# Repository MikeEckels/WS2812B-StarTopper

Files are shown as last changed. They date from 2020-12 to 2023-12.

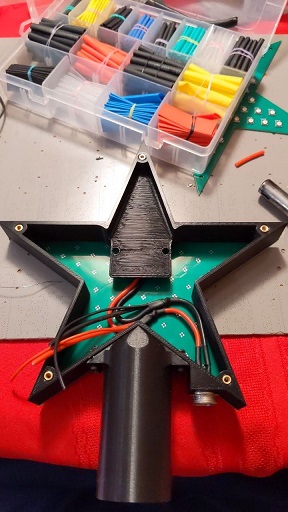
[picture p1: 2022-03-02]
Photos/Star/Wiring.jpg

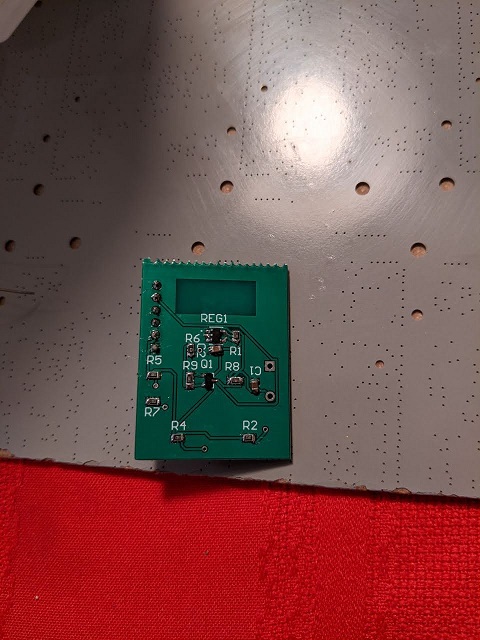
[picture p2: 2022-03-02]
Photos/Star/ESPBack.jpg

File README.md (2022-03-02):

# WS2812B-StarTopper
 RGB Christmas tree star topper with 126 individually adressable WS2812B LED's. The main controller is based off of an esp8266-12E embedded into a custom PCB to provide voltage regulation, 5v<-->3.3v level shifting, and an easy programming interface. Alternatively, the software also supports a standard ESP32Devkit. Other than the custom electronics, everything is 3D-printable.
 
 - [Pictures](https://github.com/MikeEckels/WS2812B-StarTopper/tree/main/Photos)
 - [3D Files](https://github.com/MikeEckels/WS2812B-StarTopper/tree/main/3DFiles)
 - [Altium Files](https://github.com/MikeEckels/WS2812B-StarTopper/tree/main/AltiumFiles)
 
 <p float="left">
  
  
</p>
 
 # Electronics Overview
 All schematics and PCB's were created in Altium Designer. The PCB's were sent to JLCPCB for fabrication. The heart of the system is the ESP8266-12E module. This module was embedded into a small PCB with a BSS138 level shifter for the 5v<-->3.3v conversion between the ESP and the WS2812B LED's. The module also contains a AP2112K-3.3 linear voltage regulator to power the ESP from the main 5V supply. The main star PCB contains 63 WS2812B LED's with power connected in parallel, and thier data lines in series. The ESP board connects to the first stars DIN pin, and the second star's DIN pin connects to the first star's DOUT pin. The entire system is powered by a MeanWell LPV 35-5 powersupply. If a custom PCB is not desired, a standard ESP32Devkit can be used instead.
 
 ## Schematics and Board Files
  - [PCB Files](https://github.com/MikeEckels/WS2812B-StarTopper/blob/main/AltiumFiles/)
  - [Schematic PDF](https://github.com/MikeEckels/WS2812B-StarTopper/blob/main/AltiumFiles/StarTopper.pdf)
  
 ## Power Supply
  - [Purchased Here](https://www.meanwell-web.com/en-gb/ac-dc-single-output-led-driver-constant-voltage-cv-lpv--35--5)
  - [STL's Here](https://github.com/MikeEckels/WS2812B-StarTopper/tree/main/3DFiles/STLs)
  
 # Code Overveiew
 This library provides a simple wrapper around a popular LED control library called [FastLED](https://github.com/FastLED/FastLED). This enables simple and elegant control of every LED on the star as well as the ability to create and sequence patterns. I also developed a network manager to allow for seamless transitions from one network to another. That can be found [here](https://github.com/MikeEckels/EspWifiManager).
 
 ## Features
  - Quick LED addressing using [FastLED](https://github.com/FastLED/FastLED)
  - Seamless network management [EspWifiManager](https://github.com/MikeEckels/EspWifiManager)
  - App control over the network using [Blynk](https://github.com/blynkkk/blynk-library)
 ## Available Functions
  - Star::Begin(): Initialzie all pins and setup network
    - Arguments: None
    - Return: None
  - Star::Update(): Refreshes LED's and device state.
    - Arguments: None
    - Return: None
  - Star::NextPattern(): Ques the next pattern for the next Update() call
    - Arguments: None
    - Return: None
  - Star::LoopPatterns(unsigned int nSeconds) Ques all patterns to automatically change in sequence after nSeconds
    - Arguments: unsigned int nSeconds
    - Return: None
  - Star::SetPattern(unsigned int patternNumber) Ques a specific pattern from the list
    - Arguments: unsigned int patternNumber
    - Return: None
  - Star::SetMode(bool isPattern) sets the display mode (1 = pattern mode, 0 = color mode)
    - Arguments: bool isPattern
    - Return: None
  - Star::SetColor(unsigned int r, unsigned int g, unsigned int b) sets all LEDs on the star to a desired RGB value
    - Arguments: unsigned int r,g,b
    - Reurn: None
  - Star::SetBrightness(unsigned int brightness) sets all LEDs on the star to a desired brightness
    - Arguments: unsigned int brightness
    - Return: None
  - Star::SetFramesPerSecond(unsigned int fps) sets the refresh rate for patterns when in patern mode
    - Arguments: unsigned int fps
    - Return: None
    
 # App Control
 Using the [Blynk](https://github.com/blynkkk/blynk-library) arduino library and accompanying android and apple app, a simple user interface can be made. This allows for multiple types of widgets to be setup to transfer data back and fourth between the star and the app. In this simple setup, a color picker, a brightness slider, and a pattern mode button are used to give simple wireless functionality to the star. A Terminal widget is also used to display debug/status information.
 


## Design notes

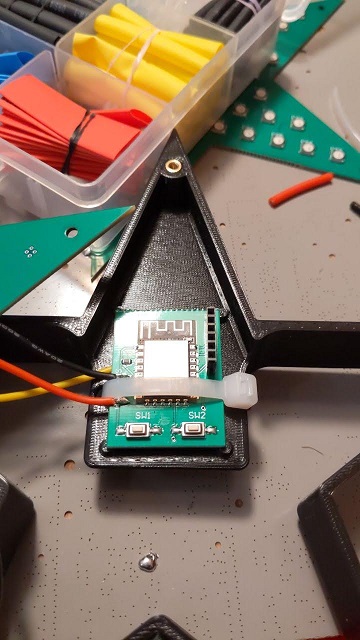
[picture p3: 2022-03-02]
Photos/Star/AttachingESP.jpg

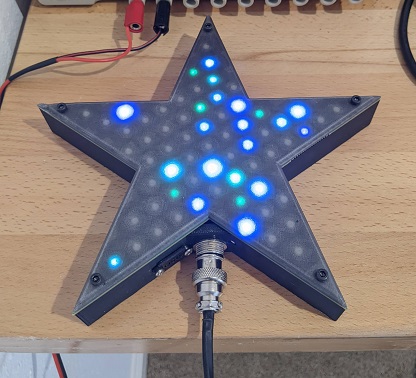
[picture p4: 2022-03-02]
Photos/Star/Version2.jpg

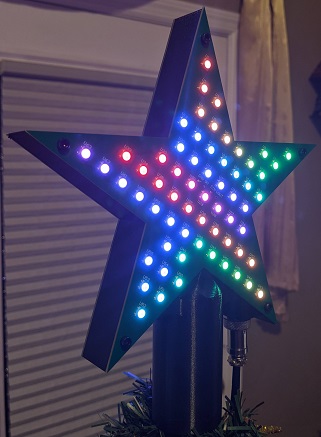
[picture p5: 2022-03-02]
Photos/Star/FinishedStar.jpg

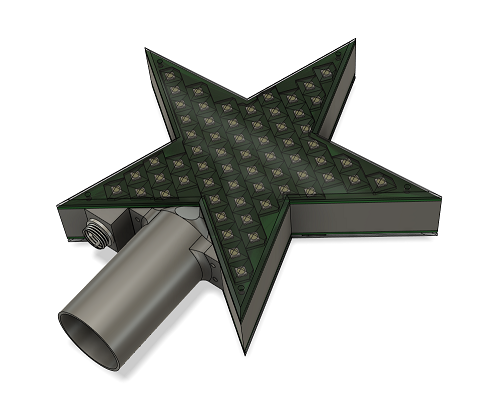
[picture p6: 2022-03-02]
Photos/Star/3DModel.PNG

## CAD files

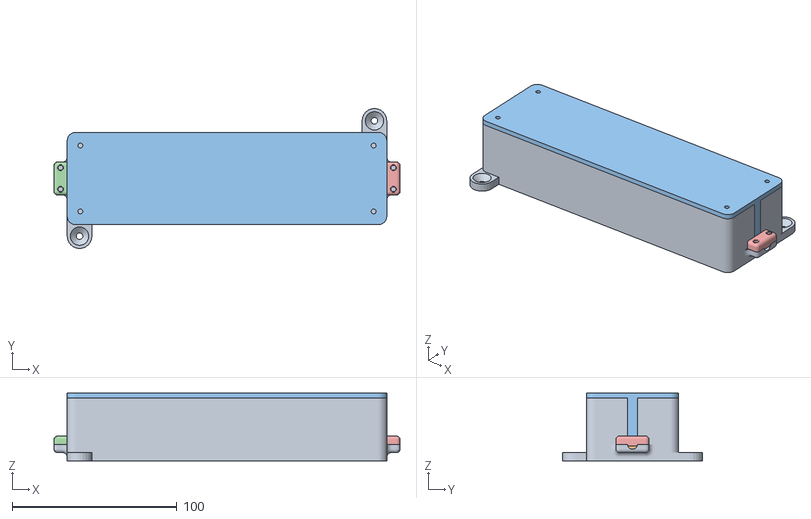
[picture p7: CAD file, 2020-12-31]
3DFiles/OBJs/PowerSupply/PSUBox.obj
210.0 x 85.0 x 41.0

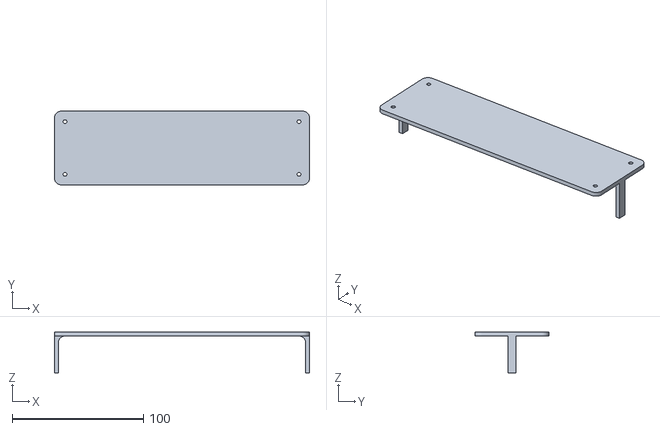
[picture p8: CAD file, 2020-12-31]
3DFiles/STLs/PowerSupply/Lid.stl
194.0 x 56.0 x 31.0

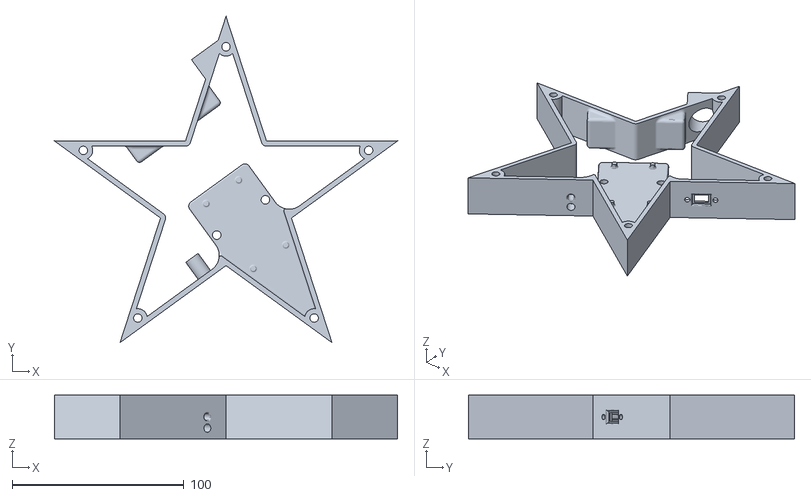
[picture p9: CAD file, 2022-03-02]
3DFiles/STLs/StarV2/Frame.stl
199.7 x 189.9 x 25.4

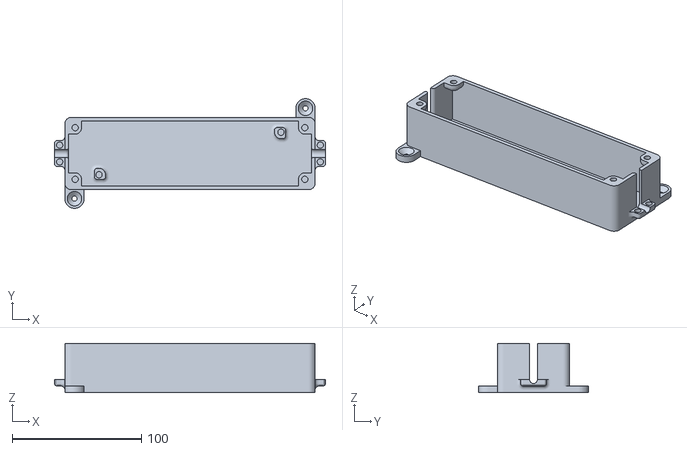
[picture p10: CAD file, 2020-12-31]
3DFiles/STLs/PowerSupply/Box.stl
210.0 x 85.0 x 38.0

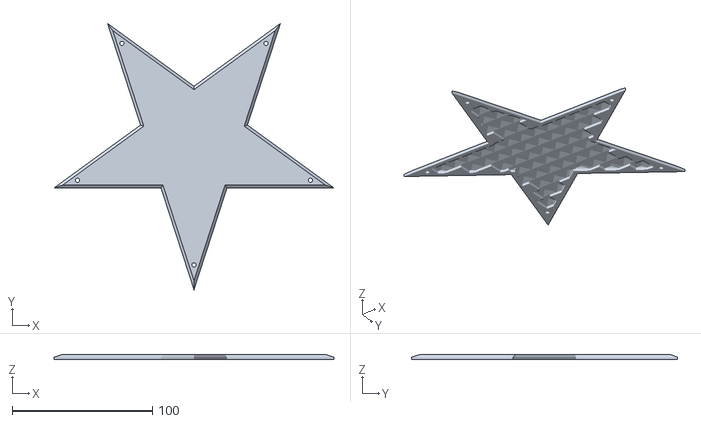
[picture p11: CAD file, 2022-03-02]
3DFiles/STLs/StarV2/Cover.stl
199.7 x 189.9 x 3.70

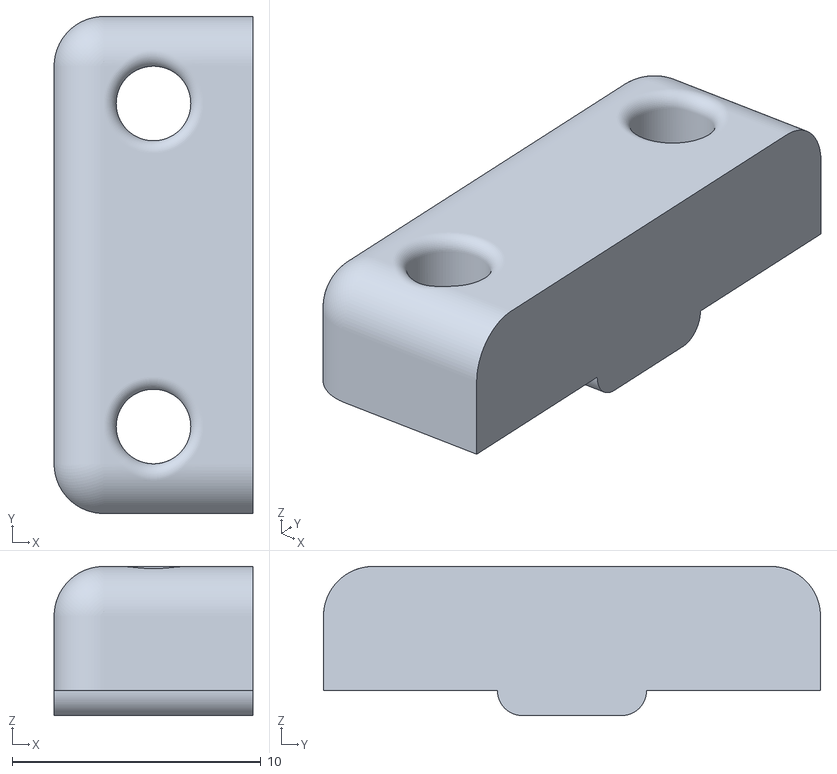
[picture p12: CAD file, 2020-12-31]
3DFiles/STLs/PowerSupply/CableRestraint.stl
8.00 x 20.0 x 6.00

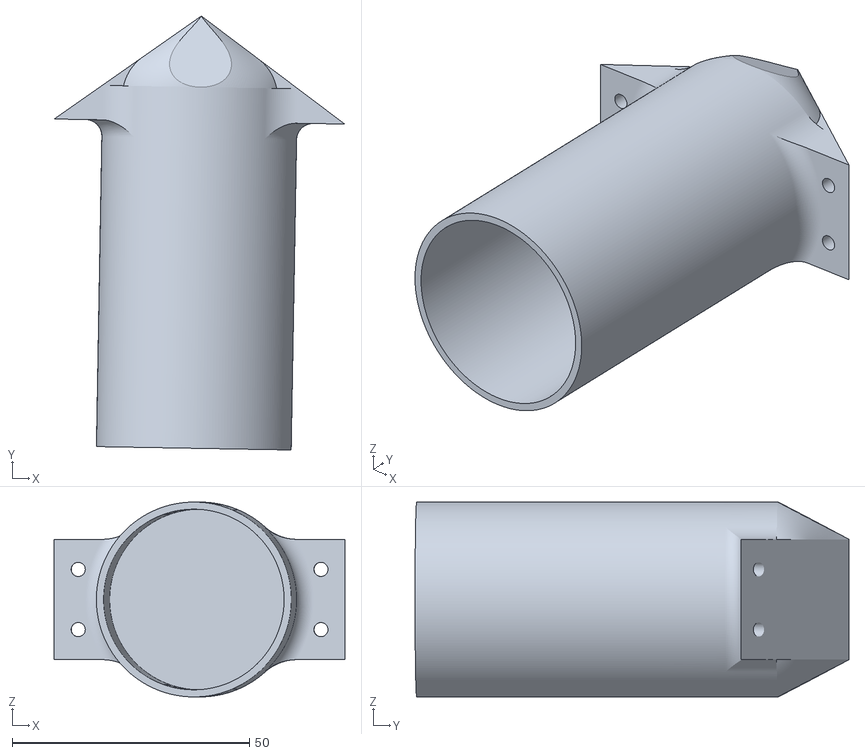
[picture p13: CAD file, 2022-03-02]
3DFiles/STLs/StarV2/PoleMount.stl
61.3 x 91.5 x 41.1

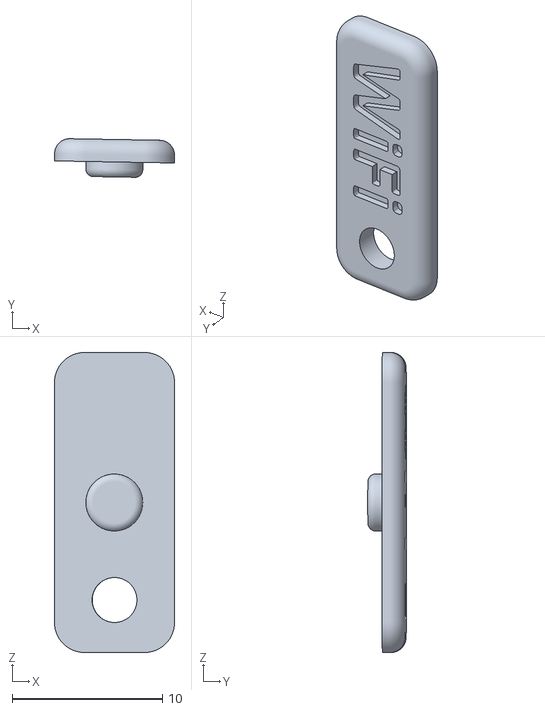
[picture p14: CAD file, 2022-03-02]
3DFiles/STLs/StarV2/ResetCover.stl
8.01 x 2.58 x 20.0

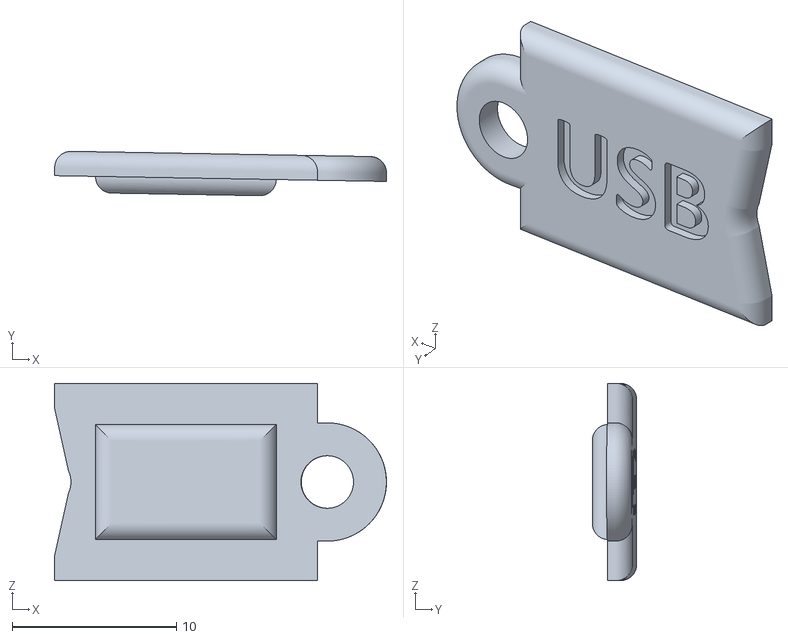
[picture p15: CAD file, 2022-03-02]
3DFiles/STLs/StarV2/USBCover.stl
20.2 x 2.70 x 12.0

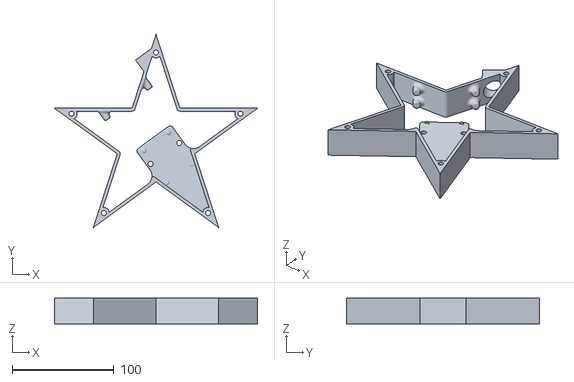
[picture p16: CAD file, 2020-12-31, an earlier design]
3DFiles/STLs/StarV1/Frame.stl
199.7 x 189.9 x 25.4

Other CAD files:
3DFiles/STLs/StarV1/PoleMount.stl
3DFiles/OBJs/PowerSupply/PSUBox.f3z
3DFiles/StarTopperV1.f3z

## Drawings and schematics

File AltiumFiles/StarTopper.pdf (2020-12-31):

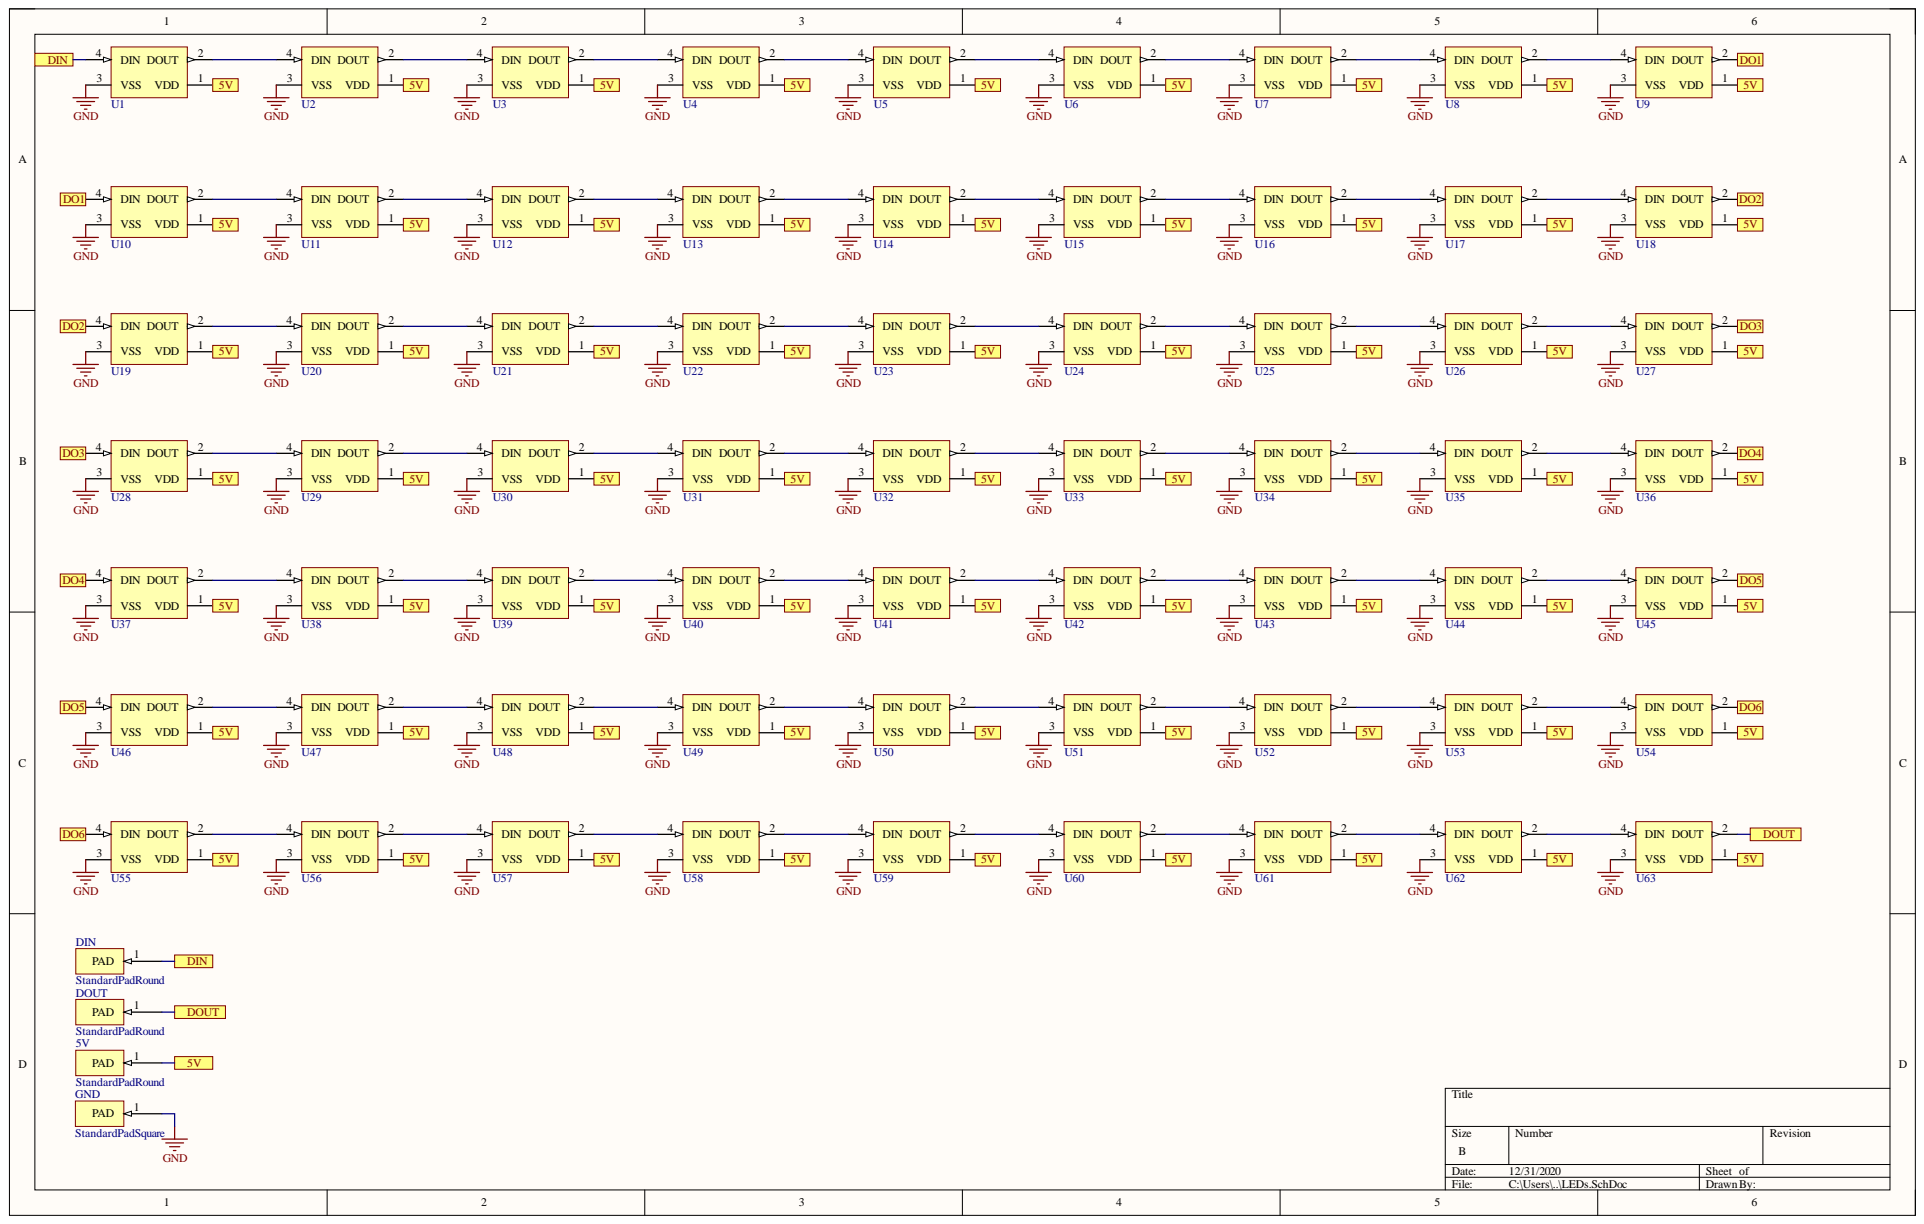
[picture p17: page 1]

DO4 | VSS 3 | VSS 3 | VSS 3 | VSS 3 | VSS 3 | VSS 3 | VSS 3 | VSS 3 | VSS 3 | DO5

DO5 | VSS 3 | VSS 3 | VSS 3 | VSS 3 | VSS 3 | VSS 3 | VSS 3 | VSS 3 | VSS 3 | DO6

DO6 | VSS 3 | VSS 3 | VSS 3 | VSS 3 | VSS 3 | VSS 3 | VSS 3 | VSS 3 | VSS 3 | DOUT

Size B | Number | Revision

Date: 12/31/2020 | Sheet of
File: C:\Users\..\LEDs.SchDoc | Drawn By:

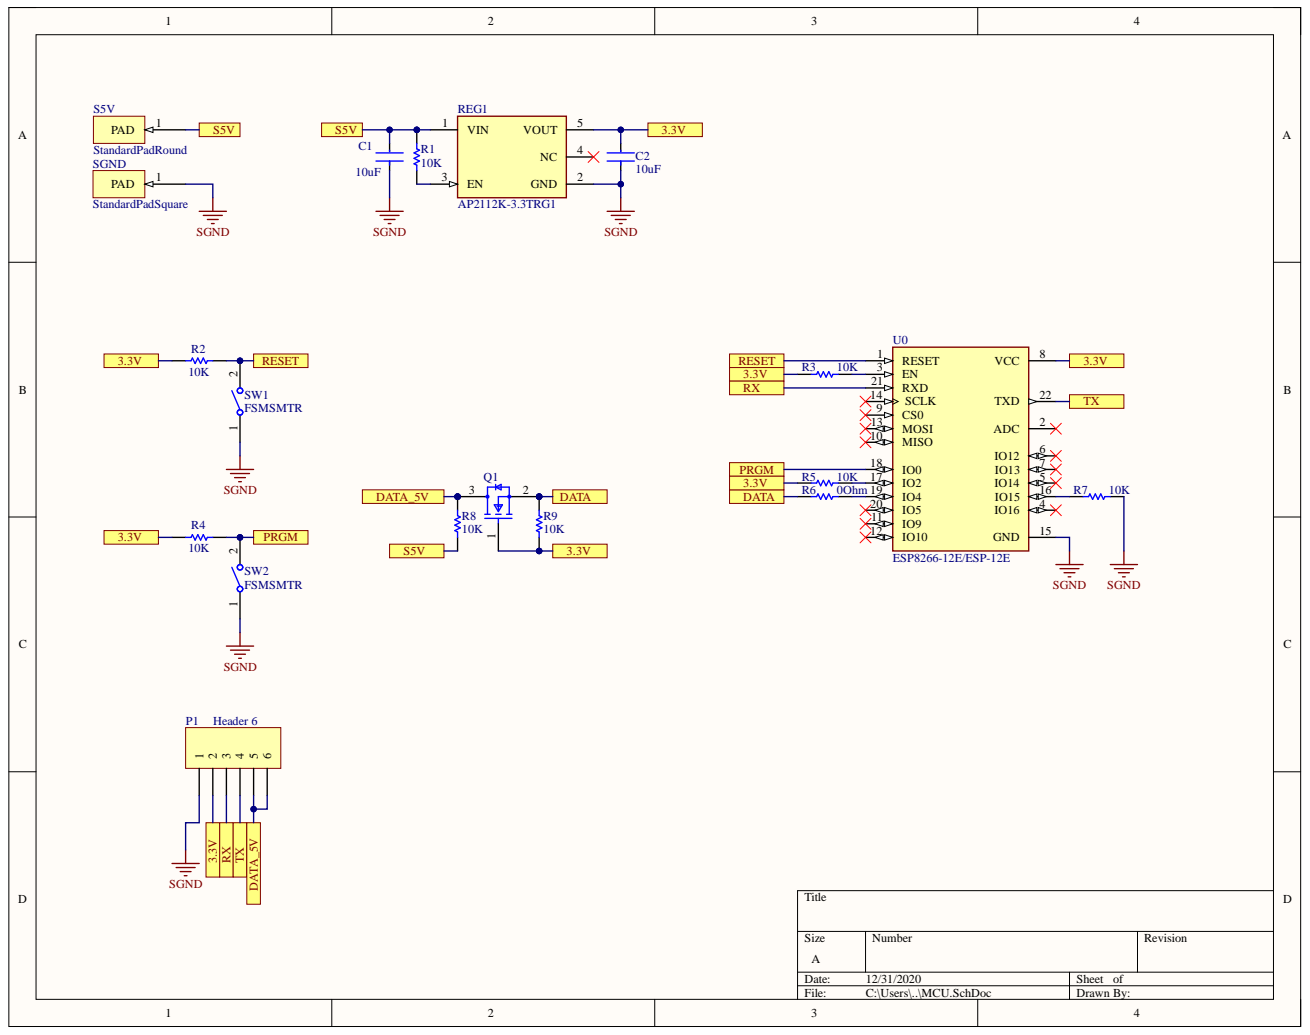
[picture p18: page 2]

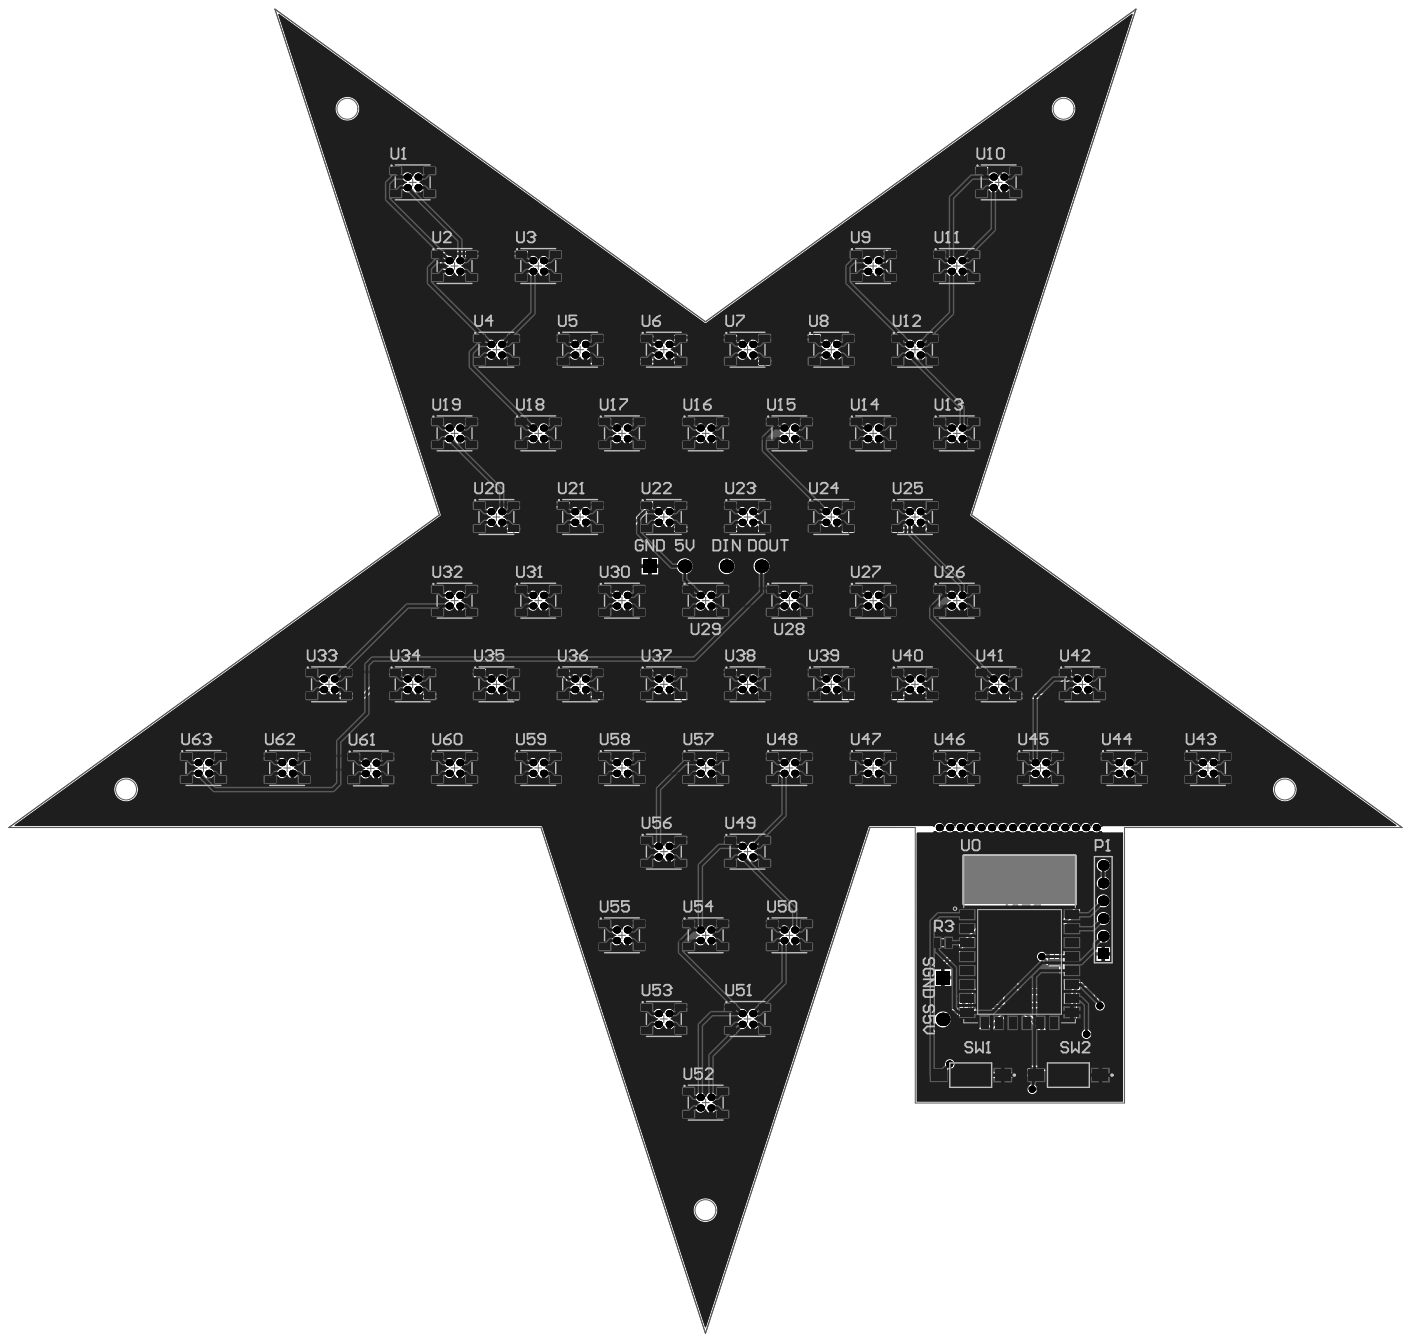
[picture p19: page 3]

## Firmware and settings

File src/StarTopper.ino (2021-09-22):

#include "Star.h"

Star StarTopper;

void setup() {
	Serial.begin(115200);
	StarTopper.begin();

	/*Either set pattern mode with a brightness*/
	StarTopper.SetMode(1);
	StarTopper.SetBrightness(50);

	/*Or set color mode with a brightnessand colors*/
	//StarTopper.SetMode(0);
	//StarTopper.SetBrightness(50);
	//StarTopper.SetColor(255, 0, 70);

	StarTopper.SetFramesPerSecond(120);

	/*If in pattern mode you can chose a specific pattern to start on(0 - 8)
	Or repeat forever if not using "LoopPatterns()"*/
	//StarTopper.SetPattern(7);
}

void loop() {
	StarTopper.Update();
	StarTopper.LoopPatterns(10);
}

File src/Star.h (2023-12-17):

#ifndef STAR_H
#define STAR_H

//#define DEV_TOPPER
//#define CHRIS_TOPPER
#define MOM_TOPPER

#ifdef DEV_TOPPER
#define BLYNK_TEMPLATE_ID "TMPLsSXg8uS6"
#define BLYNK_TEMPLATE_NAME "DevStarTopper"
#endif

#ifdef CHRIS_TOPPER
#define BLYNK_TEMPLATE_ID "TMPLsvLCbD74"
#define BLYNK_TEMPLATE_NAME "ChrisStarTopper"
#endif

#ifdef MOM_TOPPER
#define BLYNK_TEMPLATE_ID "TMPL2FI4gYD1A"
#define BLYNK_TEMPLATE_NAME "StarTopper"
#endif

#include "Arduino.h"

#ifdef ESP8266
//#include <BlynkSimpleEsp8266.h>
#include <BlynkSimpleEsp8266Fixed.h>
#define FASTLED_ESP8266_RAW_PIN_ORDER
#elif defined(ESP32)
//#include <BlynkSimpleEsp32.h>
#include <BlynkSimpleEsp32Fixed.h>
#else
#error "Unsupported Board Type. Please use ESP8266 or ESP32"
#endif

#include<functional>
#include <FastLED.h>
#include <WifiManager.h>

#define ARRAY_SIZE(A) (sizeof(A) / sizeof((A)[0]))

static bool callBlynkOnce;
static WidgetTerminal terminal(V6);

static struct colorParams_t {
	unsigned int hue = 0;
	unsigned int red = 0;
	unsigned int blue = 0;
	unsigned int green = 0;
	unsigned int brightness = 20;
}colorParams;

class Star {
private:
	//WifiManager Network Definitions
	char auth[33];
	String espSSIDPrefix = "StarTopper";
	String espPass = "";
	static const unsigned char wifiResetPin = 5;
	static const unsigned char randomSeedPin = A0;
	WifiManager networkManager;// = WifiManager(wifiResetPin, randomSeedPin);

	//Hardware Definitions
	static const unsigned char pin = 4;
	static const EOrder colorOrder = GRB;
	static const LEDColorCorrection colorCorrection = TypicalSMD5050;
	unsigned int framesPerSecond = 120;

	//Array Sizes
	static const unsigned int numPoints = 5;
	static const unsigned int numLEDsTotal = 126;
	static const unsigned int numLEDsBorder = 42;
	static const unsigned int numLEDsPerPoint = 9;
	static const unsigned int numLEDsMiddle = (numLEDsTotal / 2) - (numLEDsPerPoint * numPoints);

	//LED Arrays
	CRGB leds[numLEDsTotal];
	const unsigned int ledBorder[numLEDsBorder] = {0, 1, 2, 4, 5, 6,
												   7, 8, 9, 10,11,12,
												   24,25,40,41,42,43,
												   44,45,46,45,48,49,
												   50,51,52,54,55,57,
												   58,59,60,61,62,32,
												   33,31,19,18,3, 1};

	const unsigned int ledMiddle[numLEDsMiddle] = {16,15,14,20,21,22,
												   23,30,29,28,27,26,
												   35,36,37,38,57,56};

	const unsigned int points[numPoints][numLEDsPerPoint] = {{0, 1, 2, 3, 4, 5, 18,17,19},
															 {6, 7, 8, 9, 10,11,12,13,24},
															 {25,39,40,41,42,43,44,45,46},
															 {48,49,50,51,52,53,54,55,47},
															 {31,32,33,34,58,59,60,61,62}};

	//Member Function Pointer Array
	typedef void (Star::* tpatternFn) ();
	tpatternFn patterns[9] = { &Star::TracePattern,    &Star::BouncePattern,    &Star::JugglePattern,
							   &Star::RainbowPattern,  &Star::GRainbowPattern,  &Star::ConfettiPattern,
							   &Star::PinwheelPattern, &Star::StarburstPattern, &Star::RasterizePattern };
	
	//Visual Parameters
	bool apError = false;
	bool patternMode = 0;
	unsigned int currentPattern = 0;

	void WifiError();
	void TracePattern();
	void BouncePattern();
	void JugglePattern();
	void RainbowPattern();
	void GRainbowPattern();
	void ConfettiPattern();
	void PinwheelPattern();
	void StarburstPattern();
	void RasterizePattern();
	void AddGlitter(fract8 chance);

	void WifiResetCallback(void);
	void WifiLoadingCallback(int status);

public:
	Star();
	void begin();
	void Update();
	void NextPattern();
	void LoopPatterns(unsigned int nSeconds);

	bool blynkConnected = false;
	bool disconnectError = false;
	
	bool GetMode();
	colorParams_t GetColors();

	void SetPattern(unsigned int patternNumber);
	void SetMode(bool isPattern);
	void SetColor(unsigned int r, unsigned int g, unsigned int b);
	void SetBrightness(unsigned int brightness);
	void SetFramesPerSecond(unsigned int fps);

};

#endif //STAR_H

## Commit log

2020-12-31 added altium files and changed src directory
    [LEDs.SchDoc, MCU.SchDoc, Star.PcbDoc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]
2020-12-31 Added 3D files
    [Frame.stl, PoleMount.stl, StarTopper.f3z]
2020-12-31 added power supply 3D models
    [Box.stl, CableRestraint.stl, Frame.stl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]
2020-12-31 Removed .obj form gitignore
    [PSUBox.obj]
2021-08-24 Updated to use library, added error state
    [Star.h]
2021-09-14 Fixed callbacks to not require static methods
    [Star.h]
2021-09-22 Fixed server sync issues
    [Star.h, StarTopper.ino]
2021-09-23 Fixed bugs with terminal and animations
    [Star.h]
2022-03-02 Updated to V2
    [Cover.stl, Frame.stl, PoleMount.stl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]
